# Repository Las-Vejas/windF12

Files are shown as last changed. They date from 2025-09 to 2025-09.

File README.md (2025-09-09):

# windF12
A 12 key F row replacement for people that use 60% keyboards.

***

# What is it?
The windF12 is an F-row for people that use a 60% keyboard or play Minecraft on a MacBook like me.
It's main purpose is to provide the F keys to the user (duh).
It can be used wired or wirelessly depending on what Seeed Xiao you pick.
For wired (or ambitious wireless) users you can also add SK6812MINI-E leds under the keys for cool lighting effects.

***

# Components
This keyboard needs:
- 12 MX switches
- 12 1N4148 SOD-123 diodes
- 1 seeed XIAO
- optionally 12 SK6812MINI-E Leds
- 1 PCB

***

# Images
***
## PCB
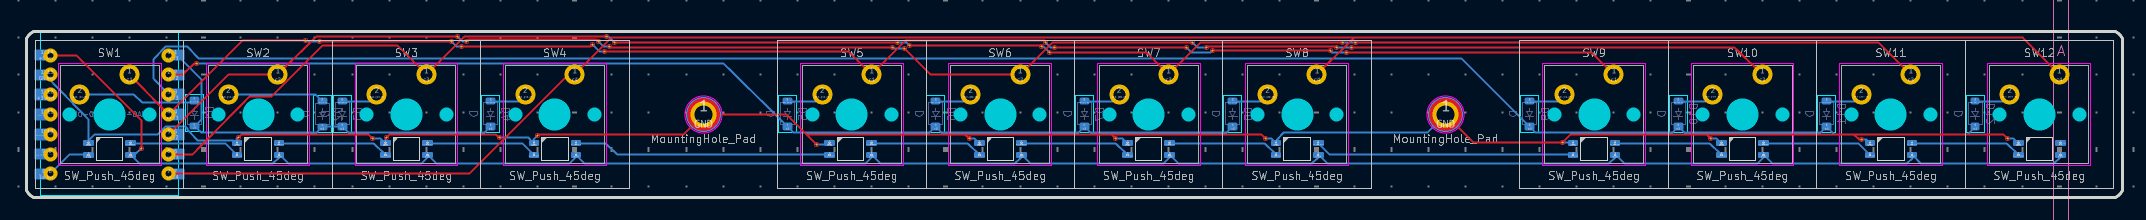
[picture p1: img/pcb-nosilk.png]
<br>
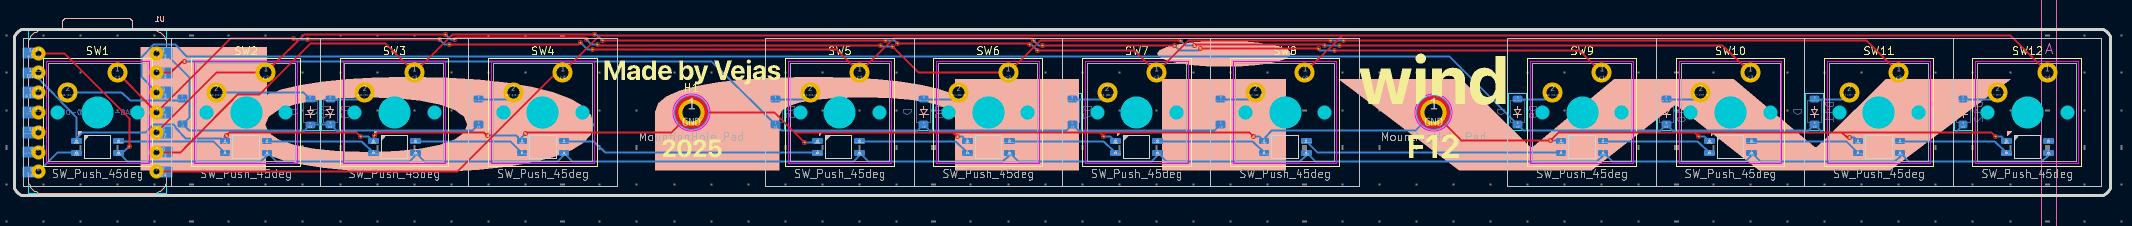
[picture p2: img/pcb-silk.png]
<br>

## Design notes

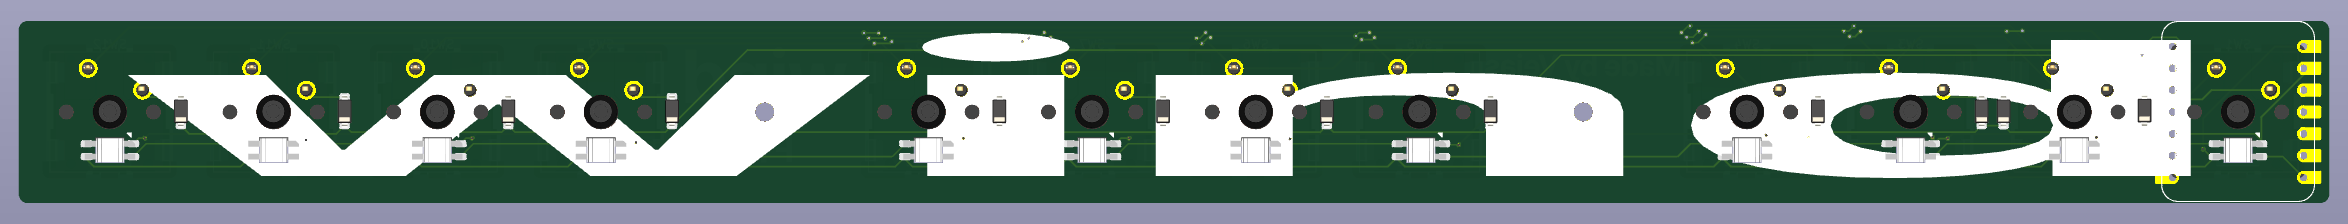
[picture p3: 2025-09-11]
img/pcb-3d-back.png

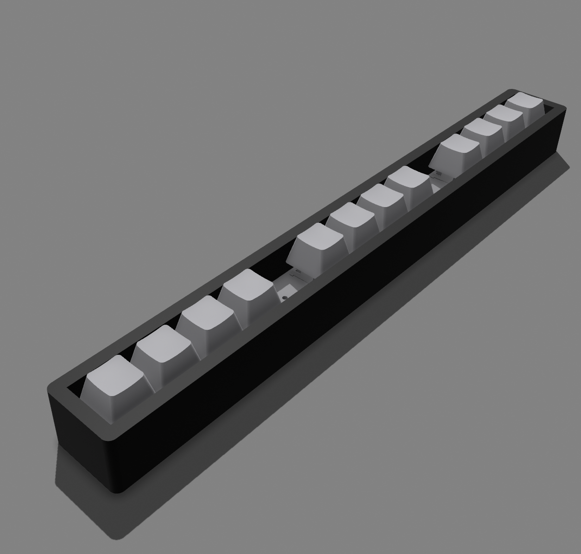
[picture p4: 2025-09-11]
img/windF12-1.png

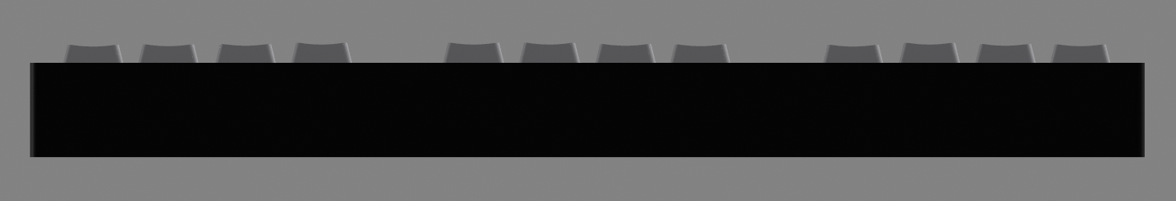
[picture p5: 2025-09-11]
img/windF12-3.png

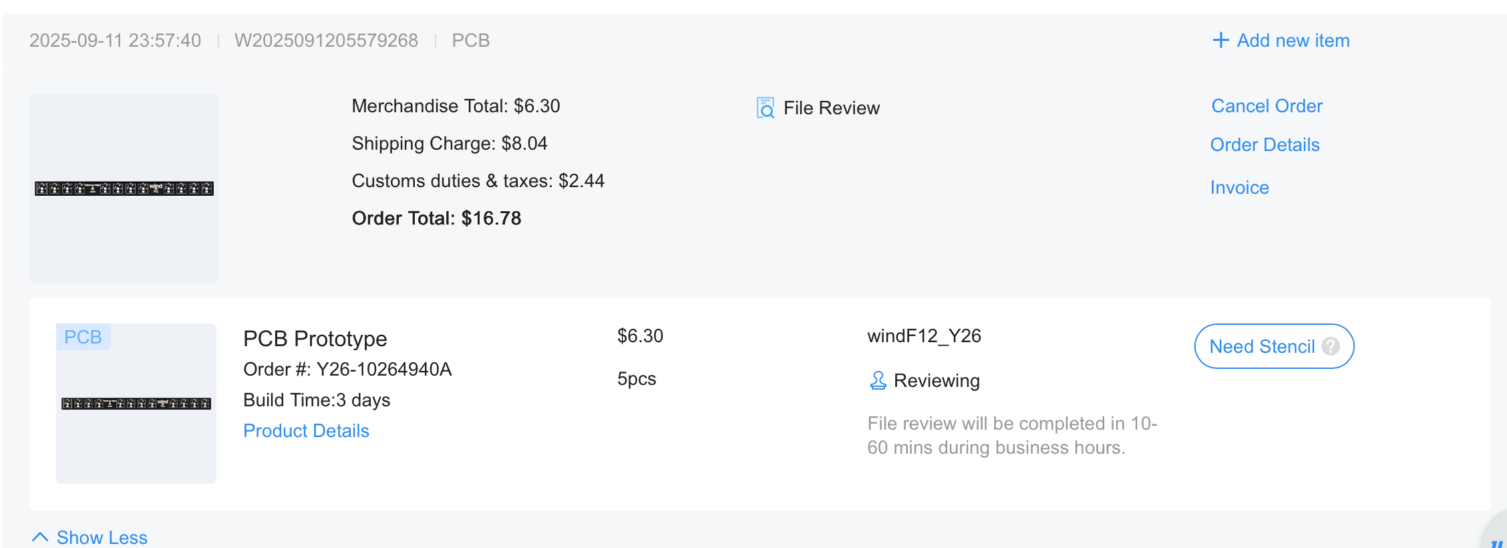
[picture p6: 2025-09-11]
jlc.png

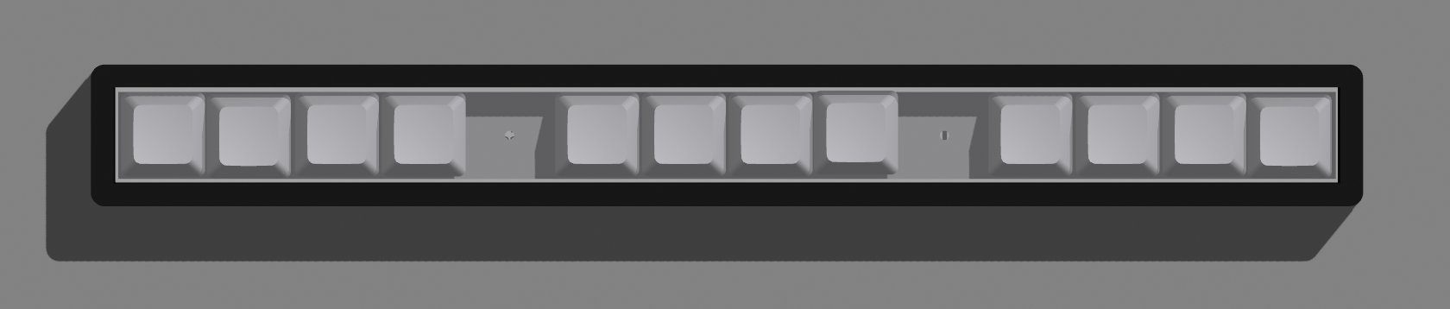
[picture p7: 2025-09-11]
img/windF12-2.png

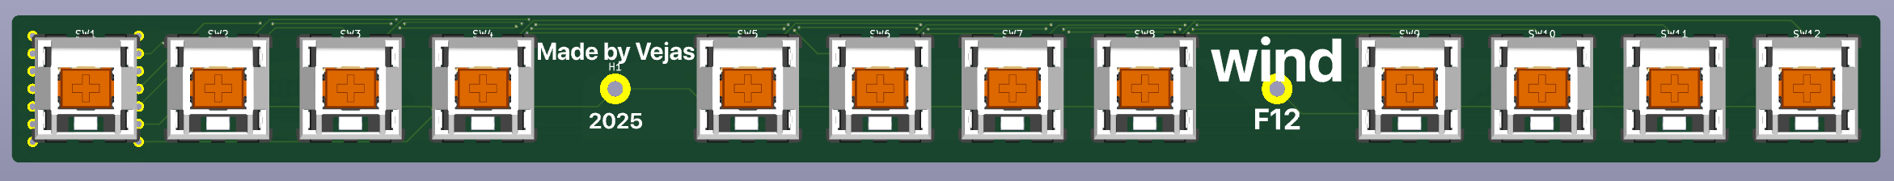
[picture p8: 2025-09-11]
img/pcb-3d-front.png

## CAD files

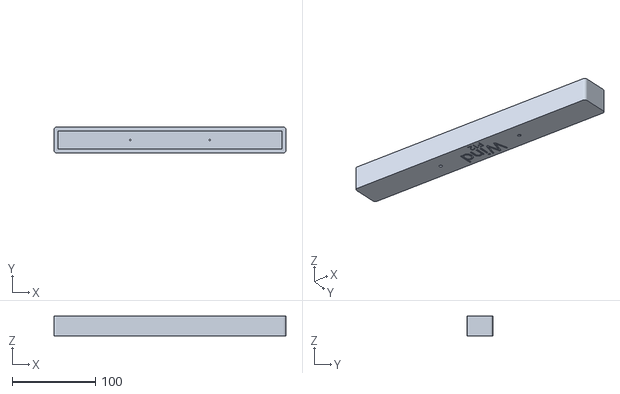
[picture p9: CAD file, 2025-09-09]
3d/plate.stl
278.7 x 31.1 x 23.6

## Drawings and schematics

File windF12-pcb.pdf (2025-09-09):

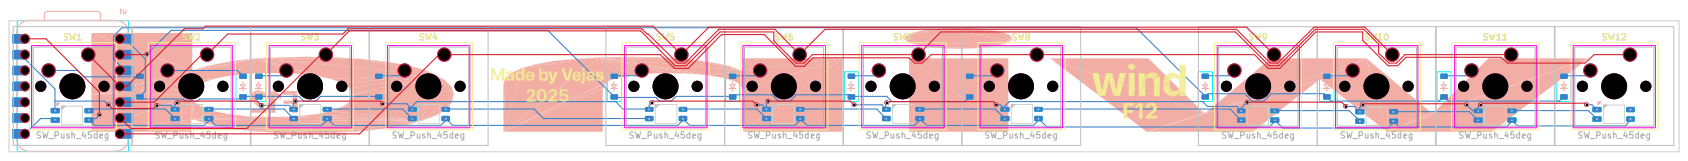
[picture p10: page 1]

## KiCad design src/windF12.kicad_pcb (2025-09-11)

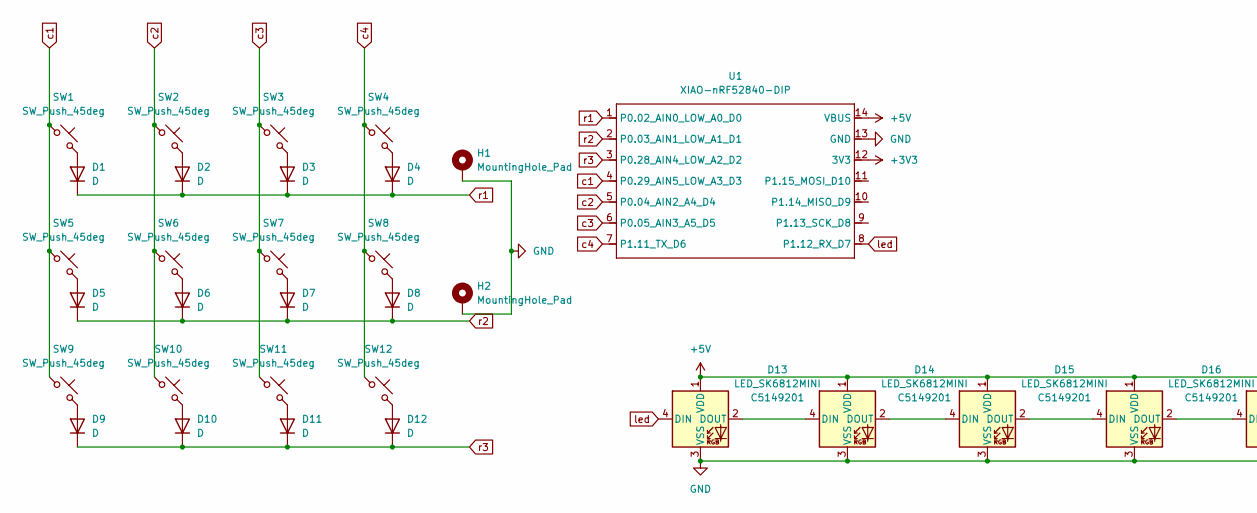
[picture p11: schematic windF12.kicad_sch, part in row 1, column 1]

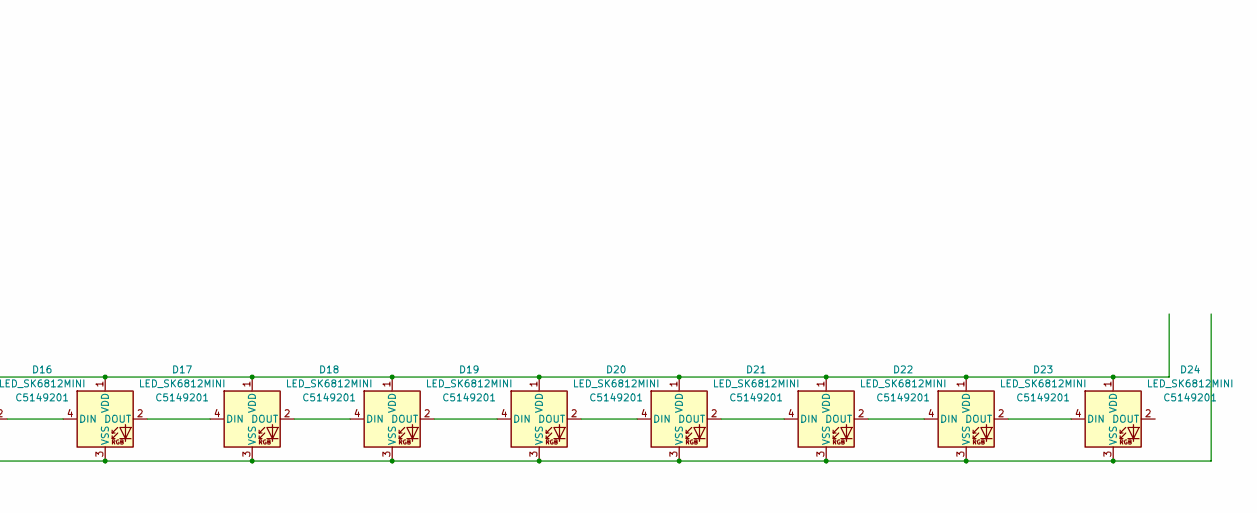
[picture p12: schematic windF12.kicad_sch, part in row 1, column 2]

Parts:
D1, D2, D3, D4, D5, D6, D7, D8, D9, D10, D11, D12: D; Diode_SOD-123
D13, D14, D15, D16, D17, D18, D19, D20, D21, D22, D23, D24: LED_SK6812MINI; LCSC C5149201
H1, H2: MountingHole_Pad; MountingHole_2.2mm_M2_Pad
SW1, SW2, SW3, SW4, SW5, SW6, SW7, SW8, SW9, SW10, SW11, SW12: SW_Push_45deg; SW_Cherry_MX_1.00u_PCB
U1: XIAO-nRF52840-DIP

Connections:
+3V3: U1.12 (3V3)
+5V: D13.1 (VDD), D14.1 (VDD), D15.1 (VDD), D16.1 (VDD), D17.1 (VDD), D18.1 (VDD), D19.1 (VDD), D20.1 (VDD), D21.1 (VDD), D22.1 (VDD), D23.1 (VDD), D24.1 (VDD), U1.14 (VBUS)
GND: D13.3 (VSS), D14.3 (VSS), D15.3 (VSS), D16.3 (VSS), D17.3 (VSS), D18.3 (VSS), D19.3 (VSS), D20.3 (VSS), D21.3 (VSS), D22.3 (VSS), D23.3 (VSS), D24.3 (VSS), H1.1, H2.1, U1.13 (GND)
unnamed: D1.2 (A), SW1.2
unnamed: D2.2 (A), SW2.2
unnamed: D3.2 (A), SW3.2
unnamed: D4.2 (A), SW4.2
unnamed: D5.2 (A), SW5.2
unnamed: D6.2 (A), SW6.2
unnamed: D7.2 (A), SW7.2
unnamed: D8.2 (A), SW8.2
unnamed: D9.2 (A), SW9.2
unnamed: D10.2 (A), SW10.2
unnamed: D11.2 (A), SW11.2
unnamed: D12.2 (A), SW12.2
unnamed: D13.2 (DOUT), D14.4 (DIN)
unnamed: D14.2 (DOUT), D15.4 (DIN)
unnamed: D15.2 (DOUT), D16.4 (DIN)
unnamed: D16.2 (DOUT), D17.4 (DIN)
unnamed: D17.2 (DOUT), D18.4 (DIN)
unnamed: D18.2 (DOUT), D19.4 (DIN)
unnamed: D19.2 (DOUT), D20.4 (DIN)
unnamed: D20.2 (DOUT), D21.4 (DIN)
unnamed: D21.2 (DOUT), D22.4 (DIN)
unnamed: D22.2 (DOUT), D23.4 (DIN)
unnamed: D23.2 (DOUT), D24.4 (DIN)
c1: SW1.1, SW5.1, SW9.1, U1.4 (P0.29_AIN5_LOW_A3_D3)
c2: SW2.1, SW6.1, SW10.1, U1.5 (P0.04_AIN2_A4_D4)
c3: SW3.1, SW7.1, SW11.1, U1.6 (P0.05_AIN3_A5_D5)
c4: SW4.1, SW8.1, SW12.1, U1.7 (P1.11_TX_D6)
led: D13.4 (DIN), U1.8 (P1.12_RX_D7)
r1: D1.1 (K), D2.1 (K), D3.1 (K), D4.1 (K), U1.1 (P0.02_AIN0_LOW_A0_D0)
r2: D5.1 (K), D6.1 (K), D7.1 (K), D8.1 (K), U1.2 (P0.03_AIN1_LOW_A1_D1)
r3: D9.1 (K), D10.1 (K), D11.1 (K), D12.1 (K), U1.3 (P0.28_AIN4_LOW_A2_D2)

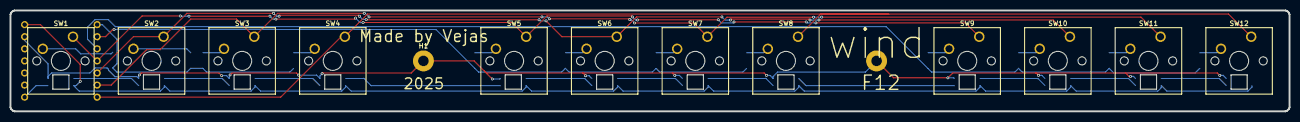
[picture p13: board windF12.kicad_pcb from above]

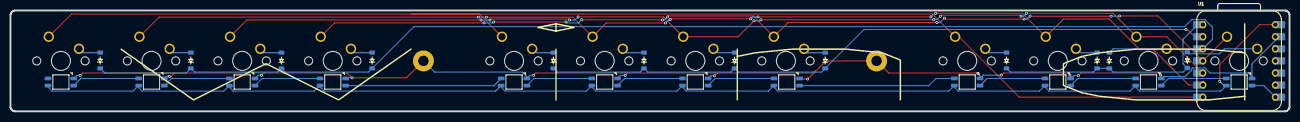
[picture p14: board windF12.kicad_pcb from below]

Board: 2 copper layers, 268.9 x 21.2 mm, 39 parts (25 on the bottom side), 33 nets.

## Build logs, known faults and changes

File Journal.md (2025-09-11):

---
Title: “windF12"
Author: “@lasvejas"
Description: “A 12 key F row replacement for people that use 60% keyboards."
Created On (d/m/y): “8/8/2025"
---

# windF12 Journal

## September 8

Whilst talking to @One For Freedom on HC slack, I was scrolling through his projects when his f row keyboard caught my eye. He told me that he made it wired, but I thought that it really shouldn’t be that hard to make it wireless, so here we go.

I used a XIAO nRF52840 because it had BT and the nRF chip is supported by zmk, so that might finally be my entry point into zmk.
There are 12 keys setup like on a normal full keyboard. I removed the overhang that the Xiao would create by showing it under the 1st switch which I’ve done on a previous keyswitch containing product.
I will solder the battery by BEFORE soldering the Xiao giving it 2 wires on the respective pads on its bottom (it will be an absolute horror to fix if it breaks).
The diodes I’m using are SOD-123 1N4148 diodes, so smd, but its fine and they aren’t that small.

That’s about it, maybe some small changes in the future.

Here are some images of my pcb:

pcb with no silkscreen<br>
pcb with silkscreen<br>

## September 9 - Silkscreen

I asked ChatGPT for some logo inspiration, and it gave me a very simple logo with ‘wind’ at the top and all me keyboard numbers under it, so I decided to make that into my branding as it looks cool and I like it really much.

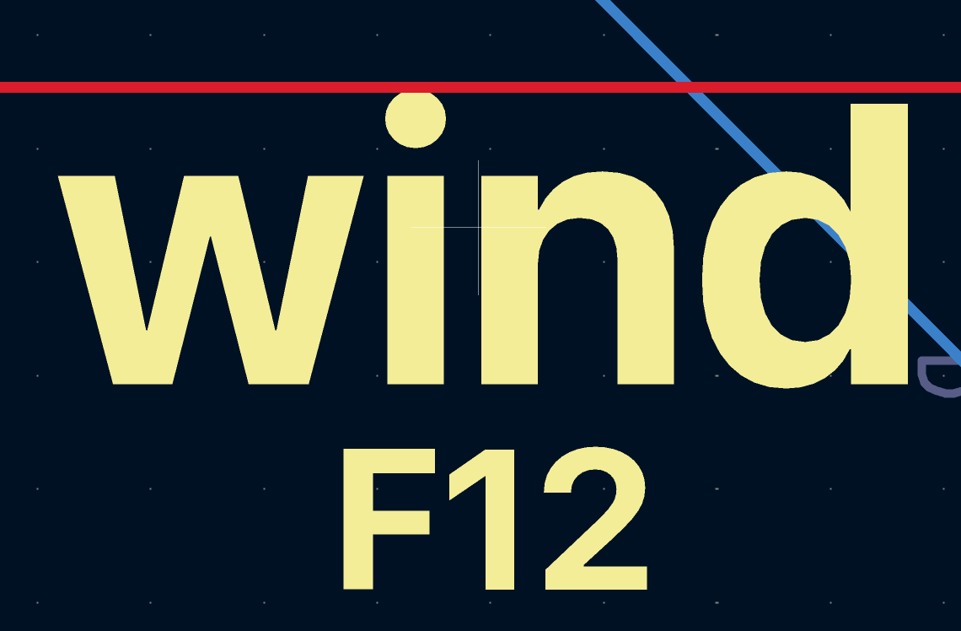
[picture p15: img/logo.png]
<br>

It’s very simple and I’ve applied it to all my projects.

When I saw the price of the Xiao BLE I was frankly shocked. So seeing that all the Xiao boards have the same footprint, I might just replace it with an rp2040 if its too expensive.

## September 10 - ~~Final revisions~~ Full revision / remake

So I’m fighting with KiCad cus its placement is weird, but I forgot to add mounting holes so I have to do that (I thought I was done :sob:) 
This was the final straw. The switches aren’t aligning correctly, and I was losing my mind.
I replaced everything, now correctly. I kept the old silkscreens but everything was replaced.

I redid my routing to be nicer looking and added mounting holes to the (new) pcb.
